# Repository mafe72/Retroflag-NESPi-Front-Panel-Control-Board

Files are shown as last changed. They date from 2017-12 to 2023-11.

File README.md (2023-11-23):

Retroflag NESPi Front Panel Control Board
===============================



This is an enhancement board for the RetroFlag NESPi case, this PCB add missing functionality to the system.

License
-------
<div align="center"><br /></div>

This project is licensed under the Attribution-NonCommercial-ShareAlike CC BY-NC-SA 4.0 license. The full legal text of the license may be found in the LICENSE.txt file in this repository. For more information about this license, please visit 
the Creative Commons Foundation (https://creativecommons.org/licenses/by-nc-sa/4.0/).

Features
--------

* Soft-shutdown Pi from power switch

* Disconnect the power from the Raspberry Pi after each shutdown (advance only)

* Custom Reset button functionality (see [Basic Usage](#basic-usage))

* Easy Temperature Control

* 2 wire fan control

* Gracefully finish EmulationStation, letting it save all metadata, in every system shutdown

* Fully compatible with Raspbian-RetroPie Pre-made images

* One-line script installation

* You can buy the latest version of this board fully assembled from [https://mini-mods.com](https://mini-mods.com/)

----------

NESPi Control Board TH
--------

Bottom Side:
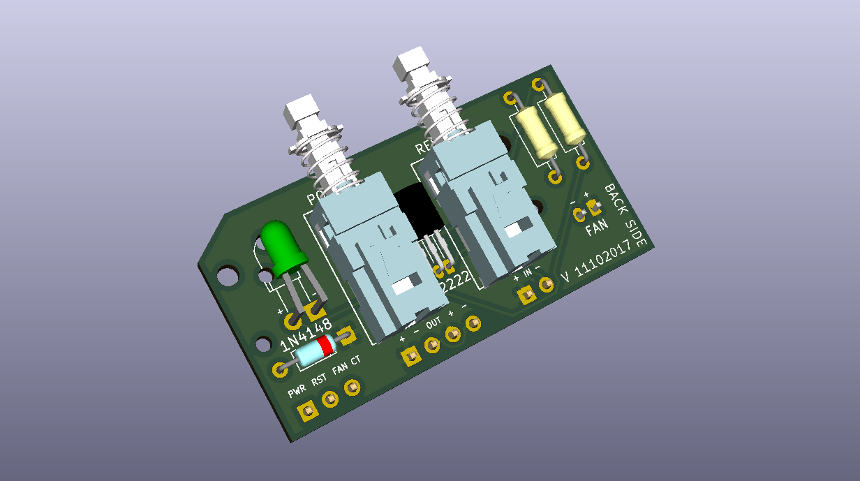
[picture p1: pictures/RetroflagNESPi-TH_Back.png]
CBottom Side


Top Side
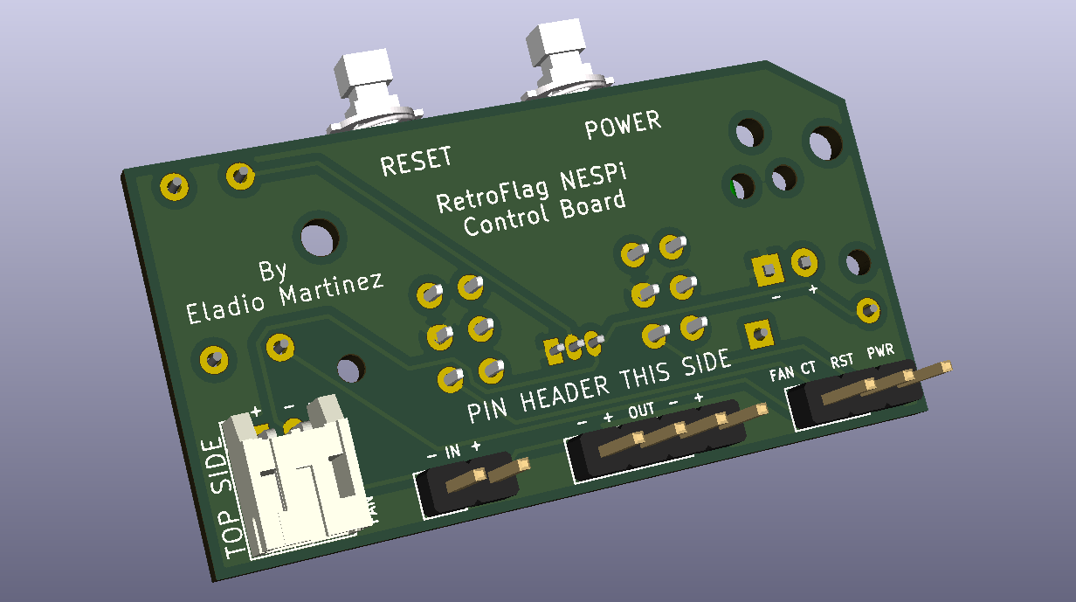
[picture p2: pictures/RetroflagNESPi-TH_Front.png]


----------

NESPi Control Board SMD
--------

Bottom Side:
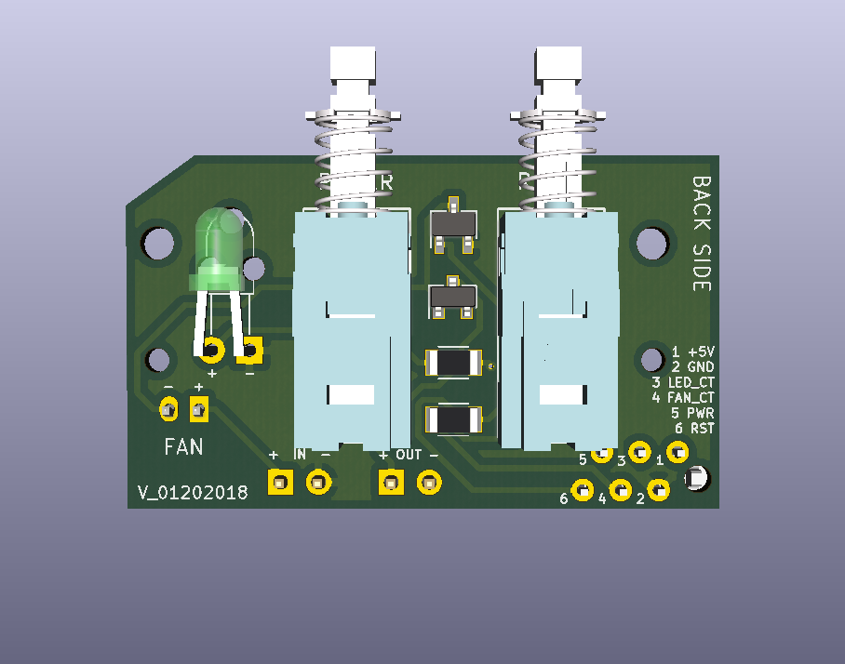
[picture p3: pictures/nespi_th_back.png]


Top Side
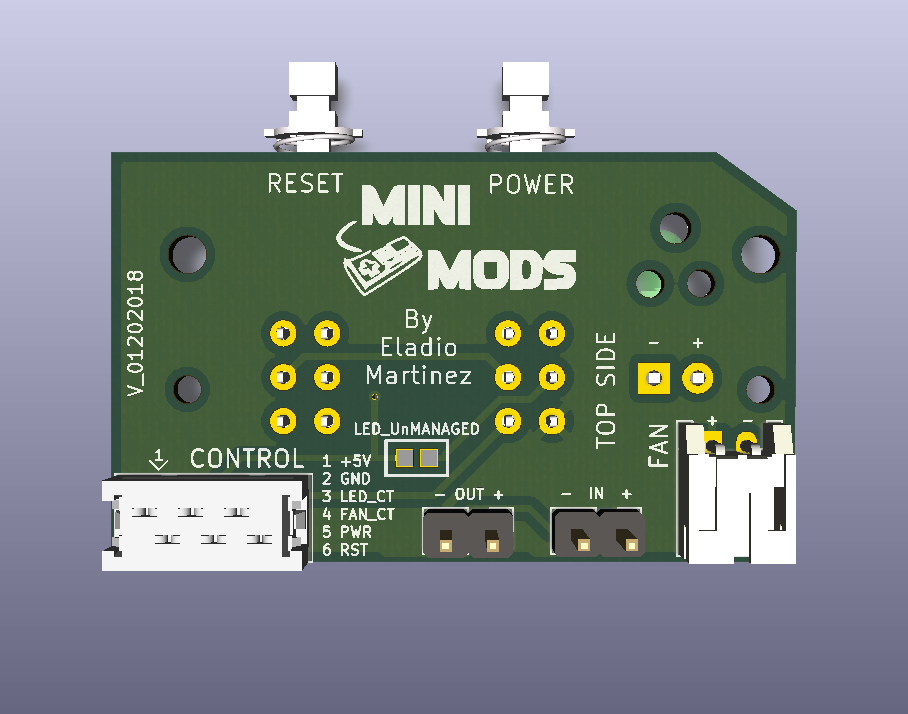
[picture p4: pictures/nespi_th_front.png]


----------

NESPi Advance Control Board SMD
--------

Bottom Side:
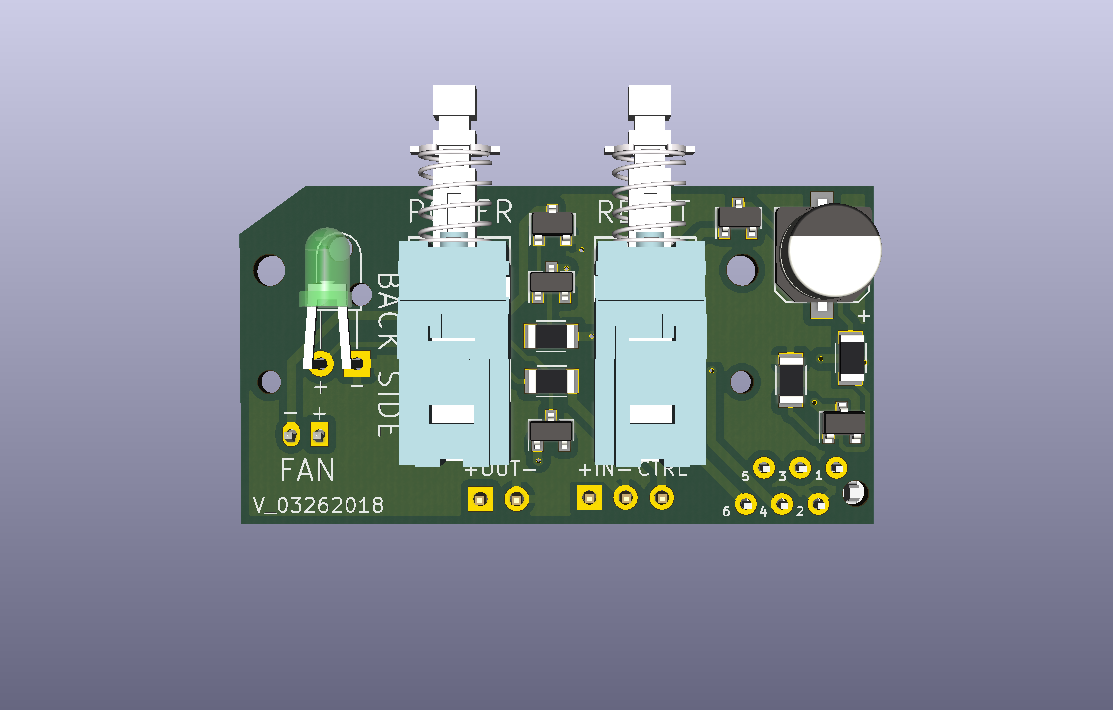
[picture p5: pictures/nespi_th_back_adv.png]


Top Side
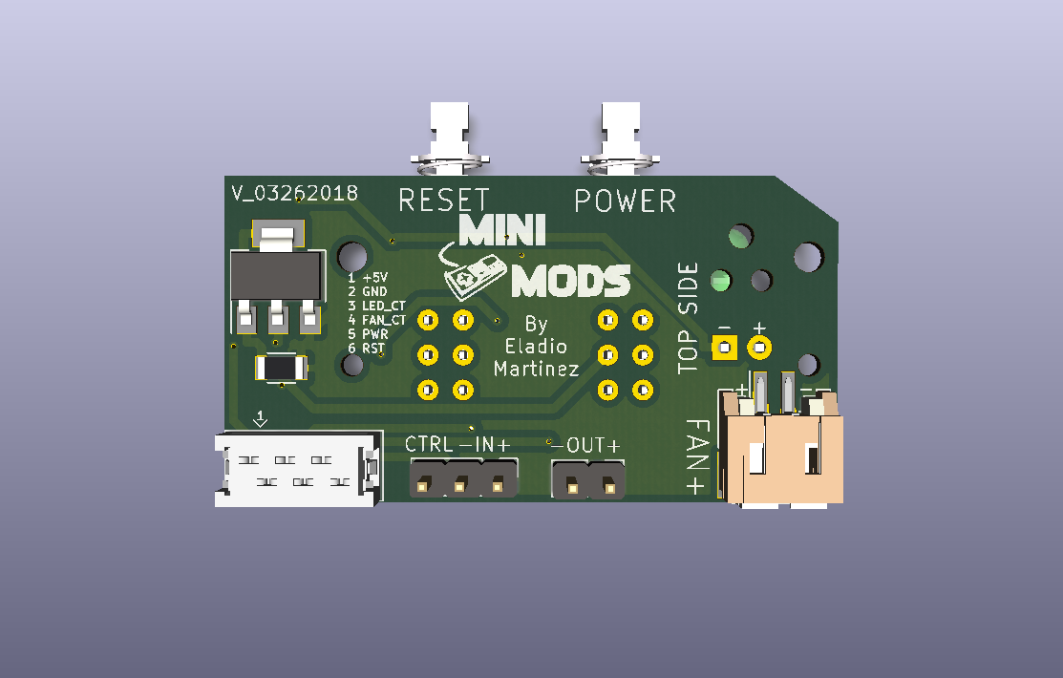
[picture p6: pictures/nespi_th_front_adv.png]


----------

YIKESHU Control Board SMD
--------

Bottom Side:
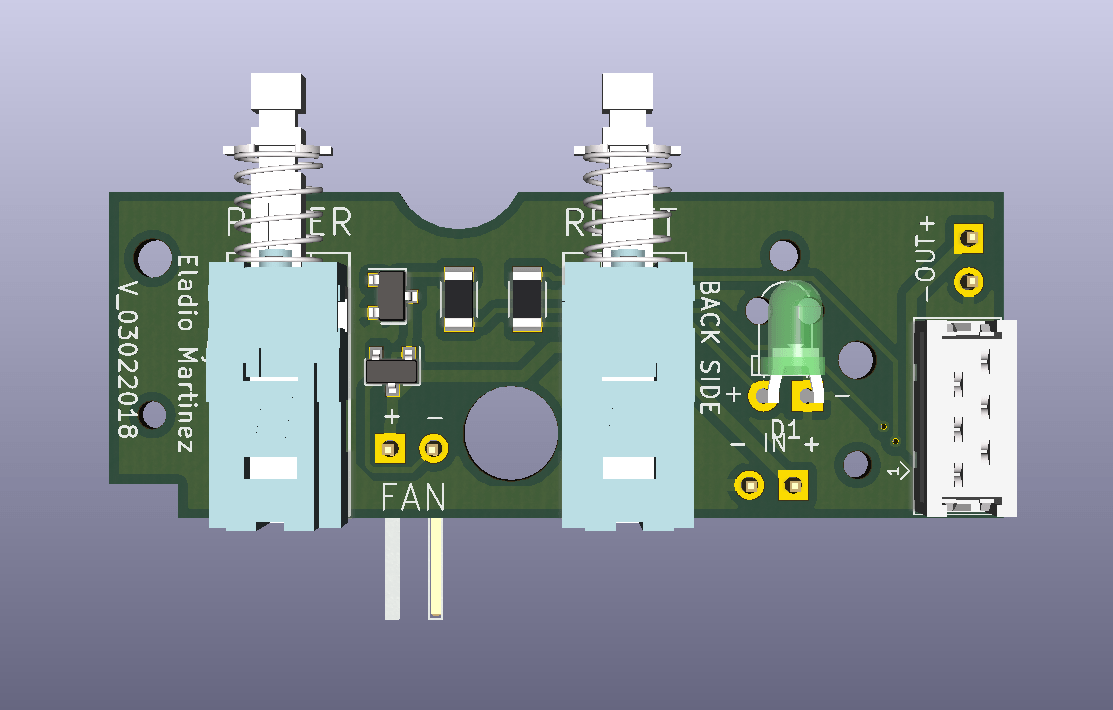
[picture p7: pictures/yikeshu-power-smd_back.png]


Top Side
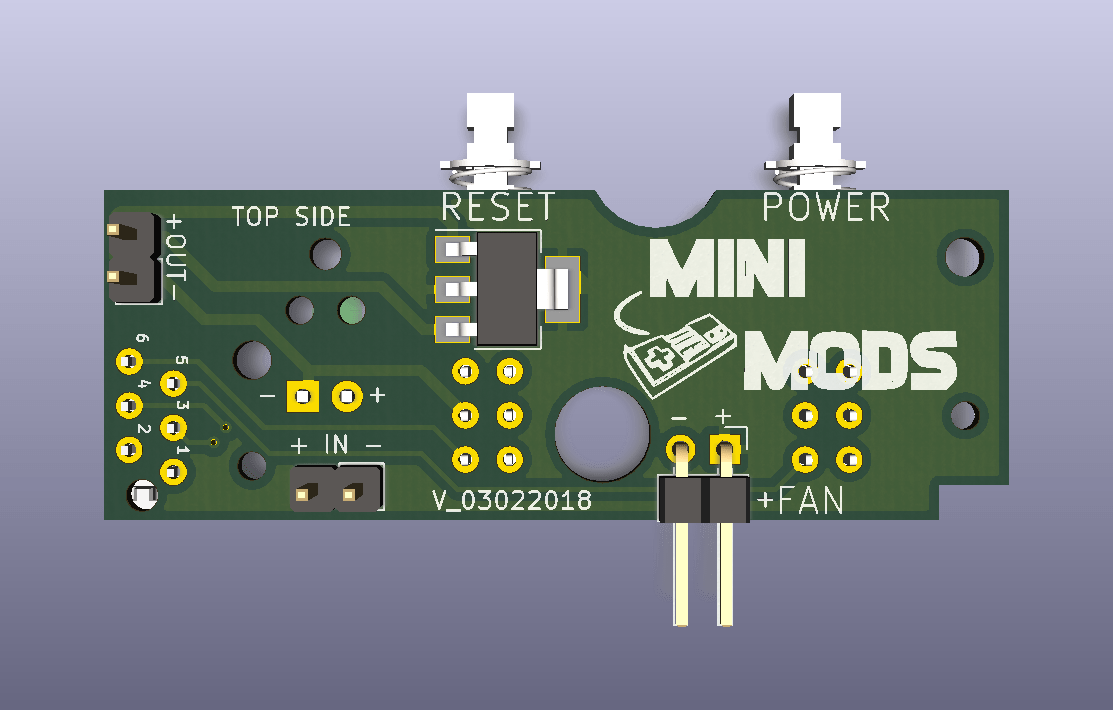
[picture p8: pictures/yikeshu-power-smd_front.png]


----------

Prerequisites
---------------------

1. RetroPie

      To install Retropie you may download the image for [Raspberry Pi 3](https://github.com/RetroPie/RetroPie-Setup/releases/download/4.2/retropie-4.2-rpi2_rpi3.img.gz "RetroPie for version RPi 2/3") and follow installation instruction at the [retropie website](https://retropie.org.uk/docs/First-Installation/#installation "RetroPie installation instructions").

2. Internet connection

      Internet access via Ethernet or to set up your internet via WiFi, you can follow the instructions [here](https://retropie.org.uk/docs/Wifi/ "RetroPie WiFi Setup").

3. Keyboard and screen, or any computer/laptop (via SSH)

      To access your Pi via SSH, you can also follow this instructions [here](https://retropie.org.uk/docs/SSH/ "Raspberry Pi SSH Setup").

Hardware Installation
---------------------
It's very important to follow the right pin configuration to prevent damage to your Pi.

  * `RST Pin` - Connect to GPIO 2 (RPI pin 3)
  * `PWR Pin` - Connect to GPIO 3 (RPI pin 5)
  * `FAN_CT Pin` - Connect to GPIO 4 (RPI pin 7)
  * `LED_CT` - Connect to GPIO 14 (RPI pin 8) 
  * `OUT + Pin` - Connect to 5V (RPI pin 4)
  * `OUT - Pin` - Connect to GND (RPI pin 6)
  * `- IN + Pin` - Source 5v
  
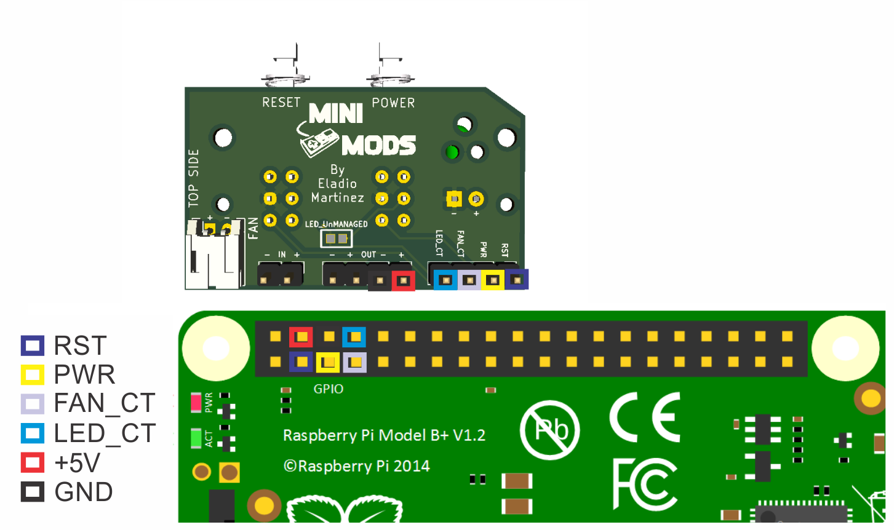
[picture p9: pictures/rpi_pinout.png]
Pin Connection


`Note: LED_CT pin is only available on PCB V_12062017 and up.`

Software Installation
---------------------

**NOTE**: This assumes that you have already connected the jumper wires to the correct PINS and the **POWER button is pressed**;
If you haven't, see the [Hardware Installation](#hardware-installation) section.

This instructions are a *step-by-step guide* to install necessary software for your **Retroflag NESPi Front Panel Control Board**.
You can setup this via SSH or using the command line interface in your RetroPie. To enter the command line interface of RetroPie, *PRESS* ***F4*** just after booting up.

----------
**NESPi & YIKESHU Control Board**

Open your terminal and type the one-line installation command below:
```bash
wget -O - "https://github.com/mafe72/Retroflag-NESPi-Front-Panel-Control-Board/raw/master/install.sh" | sudo bash
```

----------
**NESPi Advance Control Board**

Open your terminal and type the one-line installation command below:
```bash
wget -O - "https://github.com/mafe72/Retroflag-NESPi-Front-Panel-Control-Board/raw/master/install-adv.sh" | sudo bash
```

----------
The script will automatically install pertinent files and configure your Raspberry Pi to enable **Retroflag NESPi Front Panel Control Board.**
Installation will automatically reboot once all processes are completed.

After rebooting, your **Retroflag NESPi Front Panel Control Board** is now fully functional.

Software Uninstall
---------------------

This instructions are a *step-by-step guide* to uninstall the software for the **Retroflag NESPi Front Panel Control Board**.
You can setup this via SSH or using the command line interface in your RetroPie. To enter the command line interface of RetroPie, *PRESS* ***F4*** just after booting up.

----------

Open your terminal and type the one-line installation command below:
```bash
wget -O - "https://github.com/mafe72/Retroflag-NESPi-Front-Panel-Control-Board/raw/master/uninstall.sh" | sudo bash
```

The script will automatically uninstall all configuration files from your Raspberry Pi to disable the **Retroflag NESPi Front Panel Control Board.**
The uninstall script will automatically reboot once all processes are completed.

After rebooting, your **Retroflag NESPi Front Panel Control Board** will be fully deactivated.

----------
	
Basic Usage
-----------

* POWER ON
			
		While powered off
			Press (LATCH) POWER button
			LED will turn ON
			Wait for Raspberry Pi to boot		
* POWER OFF
		
		While powered on
			Press (Unlatch) POWER button
			LED will turn OFF
			Wait for Raspberry Pi to shutdown	
			Power will be disconnected from the Raspberry Pi after each shutdown (advance only)
* RESET

		Function 1
			Press button to restart EmulationStation
			No change on LED status
	
		Function 2
			Hold button for 3 seconds to reboot Console
			LED will BLINK

----------
	
Troubleshooting
-----------

If you experience under-voltage warnings use: [NorthPada Power Supply Adapter 5V 3A](https://amzn.to/2yijTcZ "NorthPada Power Supply Adapter 5V 3A").

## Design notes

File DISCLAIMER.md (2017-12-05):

# Disclaimer

## Warning!!! Installing the Retroflag NESPi Front Panel Control Board on the incorrect pins on the Raspberry Pi can damage your Pi!

Please use Retroflag NESPi Front Panel Control Board Hardware and Software at your own risk.
We do not take responsibility for any damages to your raspberry pi that may occure.

#### By installing and downloading our hardware and software you are agreeing to these terms.

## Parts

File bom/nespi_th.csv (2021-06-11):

Component | MPN | References | Value | Quantity Per PCB | Datasheet
1 | 1N4148 | D2 | 1N4148 | 1 | https://rocelec.widen.net/view/pdf/bhc41r7lwc/ONSM-S-A0003539415-1.pdf?t.download=true&u=5oefqw
2 | VAOL-3HAE4 | D1 | LED | 1 | http://static.vcclite.com/pdf/VAOL-3HAE4-LED-3mm-red.pdf
3 | 68001-203HLF | J3 | Control | 1 | https://cdn.amphenol-icc.com/media/wysiwyg/files/drawing/68000.pdf
4 | S2B-PH-KL(LF)(SN)-ND | J4 | FAN | 1 | https://www.jst-mfg.com/product/pdf/eng/ePH.pdf
5 | 68001-202HLF | J1 | Power_IN | 1 | https://cdn.amphenol-icc.com/media/wysiwyg/files/drawing/68000.pdf
6 | 68001-204HLF | J2 | Power_OUT | 1 | https://cdn.amphenol-icc.com/media/wysiwyg/files/drawing/68000.pdf
7 | PN2222 | Q1 | PN2222 NPN | 1 | https://media.digikey.com/pdf/Data%20Sheets/ON%20Semiconductor%20PDFs/PN2222.pdf
8 | MFR-25FBF52-150R | R1 | 150ohm | 1 | https://www.yageo.com/upload/media/product/products/datasheet/lr/Yageo_LR_MFR_1.pdf
9 | MFR-25FBF52-2K2 | R2 | 2K2 | 1 | https://www.yageo.com/upload/media/product/products/datasheet/lr/Yageo_LR_MFR_1.pdf
10 | PBH2UEENAGX | SW1 | PBH2UEENAGX | 1 | https://sten-eswitch-13110800-production.s3.amazonaws.com/system/asset/product_line/data_sheet/52/PBH.pdf
11 | PBH2UOANAGX | SW2 | PBH2UOANAGX | 1 | https://sten-eswitch-13110800-production.s3.amazonaws.com/system/asset/product_line/data_sheet/52/PBH.pdf

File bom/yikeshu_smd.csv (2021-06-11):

Component | MPN | References | Value | Quantity Per PCB | Datasheet
1 | VAOL-3HAE4 | D1 | LED | 1 | http://static.vcclite.com/pdf/VAOL-3HAE4-LED-3mm-red.pdf
2 | MMBD914LT1G | D2 | MMBD914 | 1 | https://www.onsemi.com/pdf/datasheet/mmbd914lt1-d.pdf
3 | 2178713-6 | J3 | Control | 1 | https://www.te.com/commerce/DocumentDelivery/DDEController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
4 | 22288022 | J4 | FAN_TH | 1 | https://www.molex.com/pdm_docs/sd/022288022_sd.pdf
5 | 68001-202HLF | J1 | Power_IN | 1 | https://cdn.amphenol-icc.com/media/wysiwyg/files/drawing/68000.pdf
6 | 68001-202HLF | J2 | Power_OUT | 1 | https://cdn.amphenol-icc.com/media/wysiwyg/files/drawing/68000.pdf
7 | MMBT2222ALT1G | Q1 | MMBT2222 NPN | 1 | https://www.onsemi.com/pdf/datasheet/mmbt2222lt1-d.pdf
8 | STN3P6F6 | Q2 | STN3P6F6 | 1 | http://www.st.com/content/ccc/resource/technical/document/datasheet/50/e3/76/4a/8a/51/48/55/DM00066885.pdf/files/DM00066885.pdf/jcr:content/translations/en.DM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
9 | RC1206JR-07150RL | R1 | 150ohm | 1 | https://www.yageo.com/upload/media/product/productsearch/datasheet/rchip/PYu-RC_Group_51_RoHS_L_11.pdf
10 | RC1206JR-072K2L | R2 | 2K2 | 1 | https://www.yageo.com/upload/media/product/productsearch/datasheet/rchip/PYu-RC_Group_51_RoHS_L_11.pdf
11 | PBH2UEENAGX | SW1 | PBH2UEENAGX | 1 | https://sten-eswitch-13110800-production.s3.amazonaws.com/system/asset/product_line/data_sheet/52/PBH.pdf
12 | PBH2UEENAGX | SW2 | PBH2UOANAGX | 1 | https://sten-eswitch-13110800-production.s3.amazonaws.com/system/asset/product_line/data_sheet/52/PBH.pdf

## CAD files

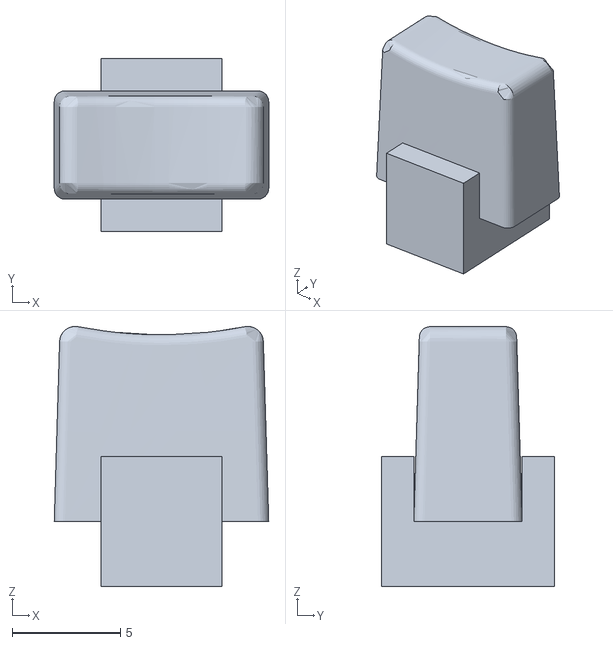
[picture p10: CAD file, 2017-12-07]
stl/EG1181-ND.stl
9.90 x 8.00 x 12.0

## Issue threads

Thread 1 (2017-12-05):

Install guide

vipermetcaff, 2017-12-05:
Need a install guide where things go on the board the bom is missing the pin headers

Closed 2017-12-06.

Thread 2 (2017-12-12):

Reset

vipermetcaff, 2017-12-12:
i'm having a problem the reset button isn't working the power button work great

mafe72, 2017-12-13:
Starting version v1.02, the reset button will no longer reboot the console, then new functionality is as follows:
- During game time, press reset button to Restart the current game.
- During game time, hold the reset button for 3 sec to Quit the current game and return to the Retropie dashboard.

vipermetcaff, 2017-12-14:
when im in a game  like nes it will only reset once then when i hit the reset again it doesnt reset the game

Closed 2017-12-13.

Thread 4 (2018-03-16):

DIY PCB/BOM informations missing + a bug

RRAlex, 2018-03-16:
I like this NesPi mod solution and thanks to this repository I was able to build a complete NesPi myself with the OSHpark & the BOM list links. I learned a few things about electronic, GPIO programming, the Pi along the way too!

It seems the PCB & BOM links went missing from the repo's master branch since than and the oshpark link ( https://oshpark.com/shared_projects/ssSJDKKQ ) is gone?

I also realized you have updated your design and was wondering if the source for the new one was going to be made available for those wanting to try their hand at weekend Pi soldering/GPIO project?
Or, simply, leave the older design up for people wanting to DIY the old fashioned way and keep the latest until you improve it again?

I'm pretty sure the DIY community is a very small one, but at the same time cool contributions could come from this repo acting as the central project of NesPi mods instead of spreading them around in various repos & forums.

Anyway, just wanted to pitch in as a fan of this project and of open source hardware communities... :)
Cheers and thanks for everything!

P.S. There is a typo on the line linked below: `apt-get` not `apt - get` :)
https://github.com/mafe72/Retroflag-NESPi-Front-Panel-Control-Board/blob/master/install.sh#L55

mafe72, 2024-02-03:
Oshpark link is permanently gone, you can get the latest Gerber files from the repo. I have fix the typo, thanks for your interest on this project.

Closed 2024-02-03.

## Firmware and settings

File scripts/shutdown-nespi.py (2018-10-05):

#####################################
# RetroFlag NESPi Control Board Script
#####################################
# Hardware:
# Board by Eladio Martinez
# http://mini-mods.com
#
#####################################
# Wiring:
#  GPIO 2  Reset Button (INPUT)
#  GPIO 3  Power Button (INPUT)
#  GPIO 4  Fan on signal (OUTPUT)
#  GPIO 14 LED on signal (OUTPUT)
#  GPIO 15 Pi_On on signal (OUTPUT)
#
#####################################
#  Required python libraries
#  sudo apt-get update
#  sudo apt-get install python-dev python-pip python-gpiozero
#  sudo pip install psutil pyserial
#
#####################################
# Basic Usage:
#  POWER ON
#    While powered off
#    Press (LATCH) POWER button
#	 LED will turn ON
#    Wait for Raspberry Pi to boot
#  POWER OFF
#    While powered on
#    Press (Unlatch) POWER button
#	 LED will turn OFF
#    Wait for Raspberry Pi to shutdown
#
# While playing a game:
#  Press RESET 
#    To reboot current game
#	 No change on LED status
#  Hold RESET for 3 seconds
#    To quit current game
#	 LED will BLINK

import RPi.GPIO as GPIO
import time
import os
import socket
from gpiozero import Button, LED
GPIO.setmode(GPIO.BCM)

resetButton = 2
powerButton = Button(3)

GPIO.setup(4, GPIO.OUT)
fan = GPIO.PWM(4, 50) #PWM frequency set to 50Hz

led = LED(14)
hold = 2
Pi_On = 15

rebootBtn = Button(resetButton, hold_time=hold)
GPIO.setup(resetButton,GPIO.IN, pull_up_down=GPIO.PUD_UP) #Reset switch
GPIO.setup(Pi_On, GPIO.OUT) #ON control
GPIO.output(Pi_On, GPIO.HIGH)

#Get CPU Temperature
def getCPUtemp():
	res = os.popen('vcgencmd measure_temp').readline()
	return (res.replace("temp=","").replace("'C\n",""))
	
while True:
	#Power / LED Control
	#When power button is unlatched turn off LED and initiate shutdown
	#if powerButton.is_pressed:
	if not powerButton.is_pressed:
		led.on()  #Take control of LED instead of relying on TX pin
	else:
		print ("Gracefully finishing EmulationStation...")
		os.system("/bin/bash /opt/RetroFlag/killes.sh")
		print ("Shutting down...")
                os.system("omxplayer -o hdmi /opt/RetroFlag/tone.mp3")
                os.system("shutdown -h now")
                break
		
	#RESET Button pressed
	#When Reset button is presed restart EmulationStation
	if rebootBtn.is_pressed:
		os.system("systemctl restart autologin@tty1.service")

	#RESET Button held
	#When Reset button is held for more then 3 sec reboot Console
	if rebootBtn.is_held:
		led.blink(.2,.2)
		os.system("reboot")

	#Fan control
	#Adjust MIN and MAX TEMP as needed to keep the FAN from kicking
	#on and off with only a one second loop
	cpuTemp = int(float(getCPUtemp()))
	fanOnTemp = 55  #Turn on fan when exceeded
	fanOffTemp = 40  #Turn off fan when under
	if cpuTemp >= fanOnTemp:
		fan.start(90) #90% duty cycle
	if cpuTemp < fanOffTemp:
		fan.stop()
time.sleep(1.00)

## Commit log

2017-11-19 Retroflag NESPi Front Panel Control Board v1.0 first commit
    [RetroflagNESPi-TH-B.Cu.gbl, RetroflagNESPi-TH-B.Mask.gbs, RetroflagNESPi-TH-B.SilkS.gbo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]
2017-11-19 add image board description
2017-11-21 Correct Mouser BOM link
2017-11-22 Add script to automatically install pertinent files and configure Retroflag NESPi Front Panel Control Board
2017-12-05 Increase silk screen font size
    [RetroflagNESPi-TH-B.Cu.gbl, RetroflagNESPi-TH-B.Mask.gbs, RetroflagNESPi-TH-B.SilkS.gbo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]
2017-12-06 Add Power Board
2017-12-06 Add Power Board image
2017-12-06 Add additional functionality to the RESET button
2017-12-07 Add 3D model for replacement button
    [EG1181-ND.stl]
2017-12-09 Update PIN information for PCB V_12062017 and up
2017-12-09 Updated to v1.02, enable led feedback for PCB V_12062017 and up
2017-12-09 Update LED functionality on Basic Usage section
2017-12-09 Add LED_CT PIN information for PCB V_12062017 and up
2018-01-17 add link to buy board
2018-01-17 update power board image
2018-01-25 Update PCB pinout
2018-02-27 Adjust fan control ON and OFF with only a one second loop
2018-02-27 Change installation flow
2018-03-01 Update installation flow
2018-03-08 Remove corrupted files
    [RetroflagNESPi-TH-B.Cu.gbl, RetroflagNESPi-TH-B.Mask.gbs, RetroflagNESPi-TH-B.SilkS.gbo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]
2018-04-02 Add NESPi Advance Control Board
2018-10-05 Update RESET button functionality
2018-10-05 add Yikeshu Control Board
2021-06-11 Update NESPi Control Board gerber
    [RetroflagNESPi-TH-B.Cu.gbl, RetroflagNESPi-TH-B.Mask.gbs, RetroflagNESPi-TH-B.SilkS.gbo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]
2021-06-11 Add Yikeshu Control Board gerber
    [YIKESHU_NESPi-SMD_Front-Panel-B.Cu.gbl, YIKESHU_NESPi-SMD_Front-Panel-B.Mask.gbs, YIKESHU_NESPi-SMD_Front-Panel-B.Paste.gbp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]
2021-06-11 Update NESPi Board Descriptions
2021-06-11 Add bom files
    [nespi_th.csv, yikeshu_smd.csv]
